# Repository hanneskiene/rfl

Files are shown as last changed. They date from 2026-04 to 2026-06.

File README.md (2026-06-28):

# rfl
4ch RC receiver/transmitter with switched diversity antennas to retrofit 35MHz remotes.

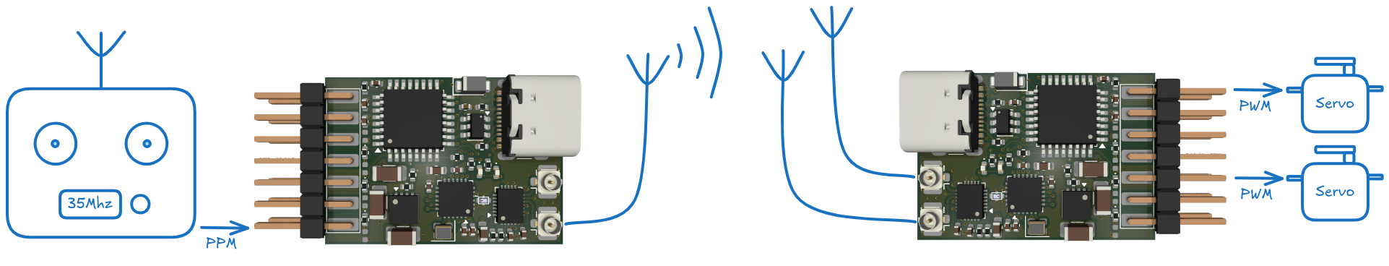
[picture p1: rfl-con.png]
Pcb Goal


- PPM input on CH3 to connect to old 35MHz internal PPM signal
- Dual U.fl connectors for antennas (single transmit, dual receive)
- 4 PWM outputs (3.3V)
- USB-C for programming 

## Parts
- SX1281 2.4GHz Transceiver IC
- SE2431L LNA/PA with up to +24 dBm
- STM32G0B1KET6N MCU
- TPS7A19 with up to 40V Vin
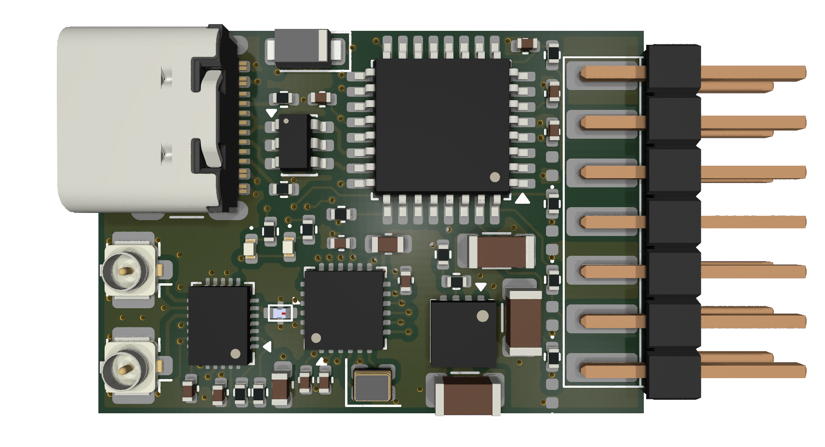
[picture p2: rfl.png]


## Assembly
QFN parts need a reflow oven/hot air station, the rest is 0402 or larger.

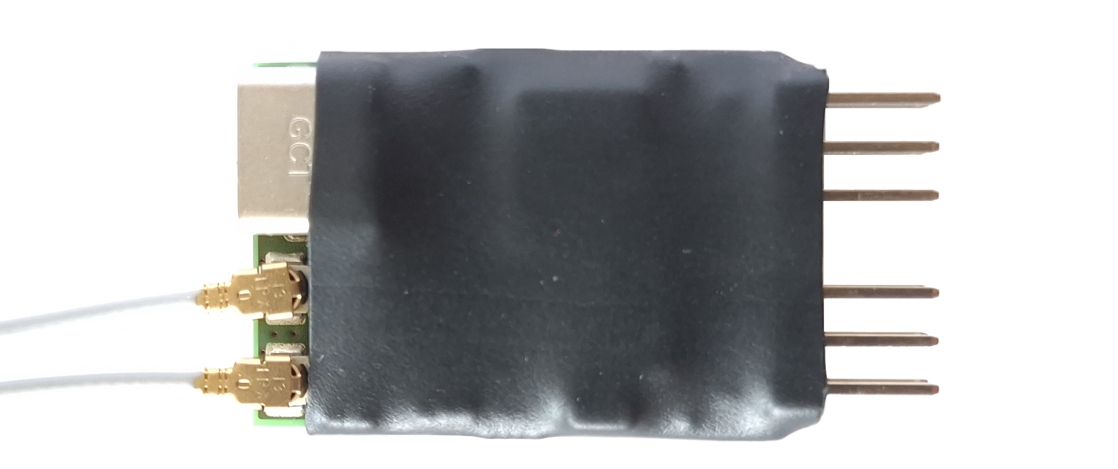
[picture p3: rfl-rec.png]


## Fimware
First prototype implementation with fixed frequency hopping table, very simple Rx-antenna diversity is "useable". The firmware currently checks for a valid PPM input if thats not found switches to receiver mode.

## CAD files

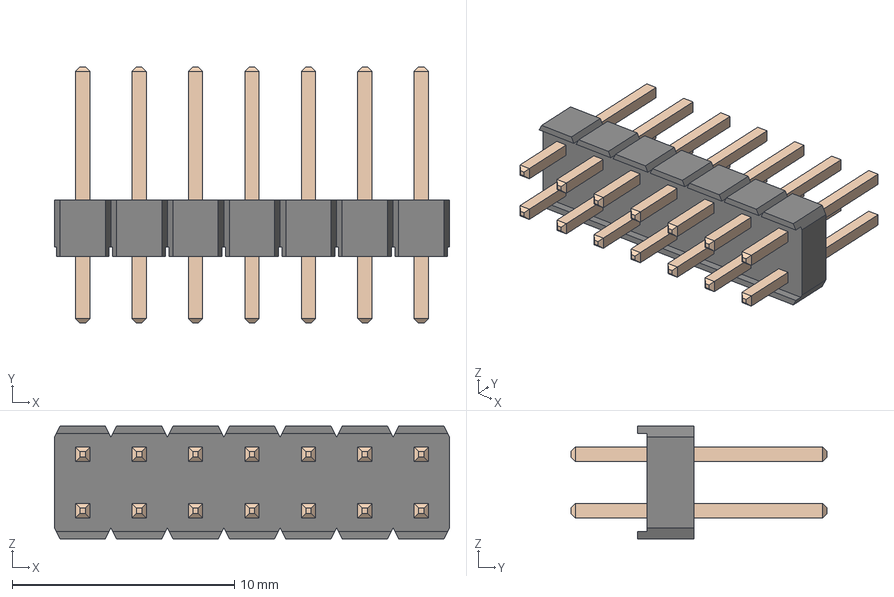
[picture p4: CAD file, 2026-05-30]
rfl/3d/Download_STP_61301421121 (rev1).stp
17.8 x 11.5 x 5.08 mm
6130xx21121_PIN x 14

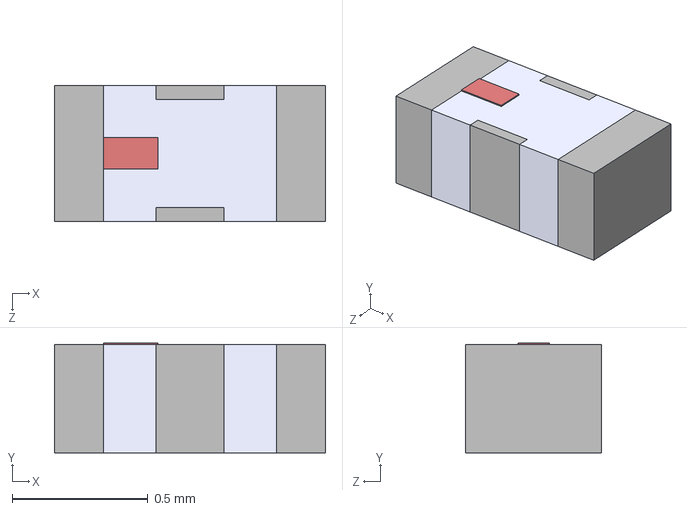
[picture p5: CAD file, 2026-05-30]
rfl/3d/2450FM07D0034001T.stp
1.00 x 0.405 x 0.5 mm

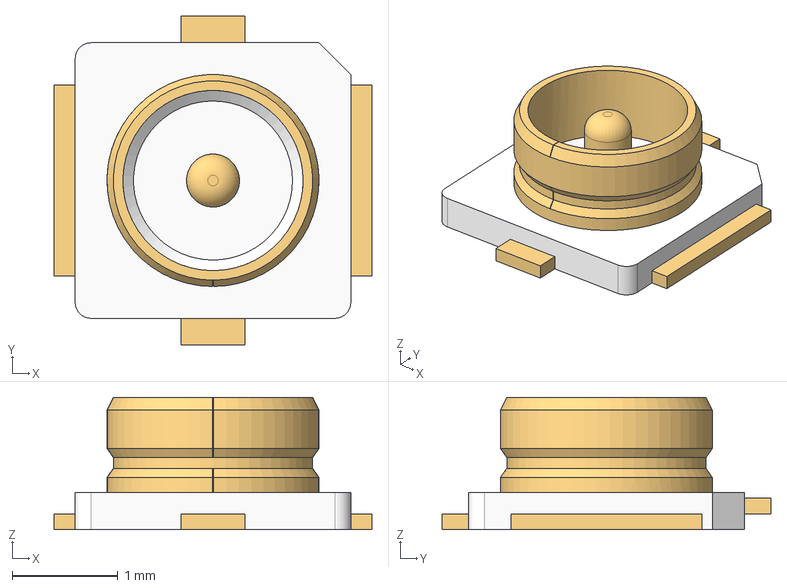
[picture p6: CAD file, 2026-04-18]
rfl/3d/Download_STP_WR-URMF_63610111x001 (rev1).stp
3.00 x 3.10 x 1.25 mm
63610111x001_Contact
63610111x001_Ground
63610111x001_Housing

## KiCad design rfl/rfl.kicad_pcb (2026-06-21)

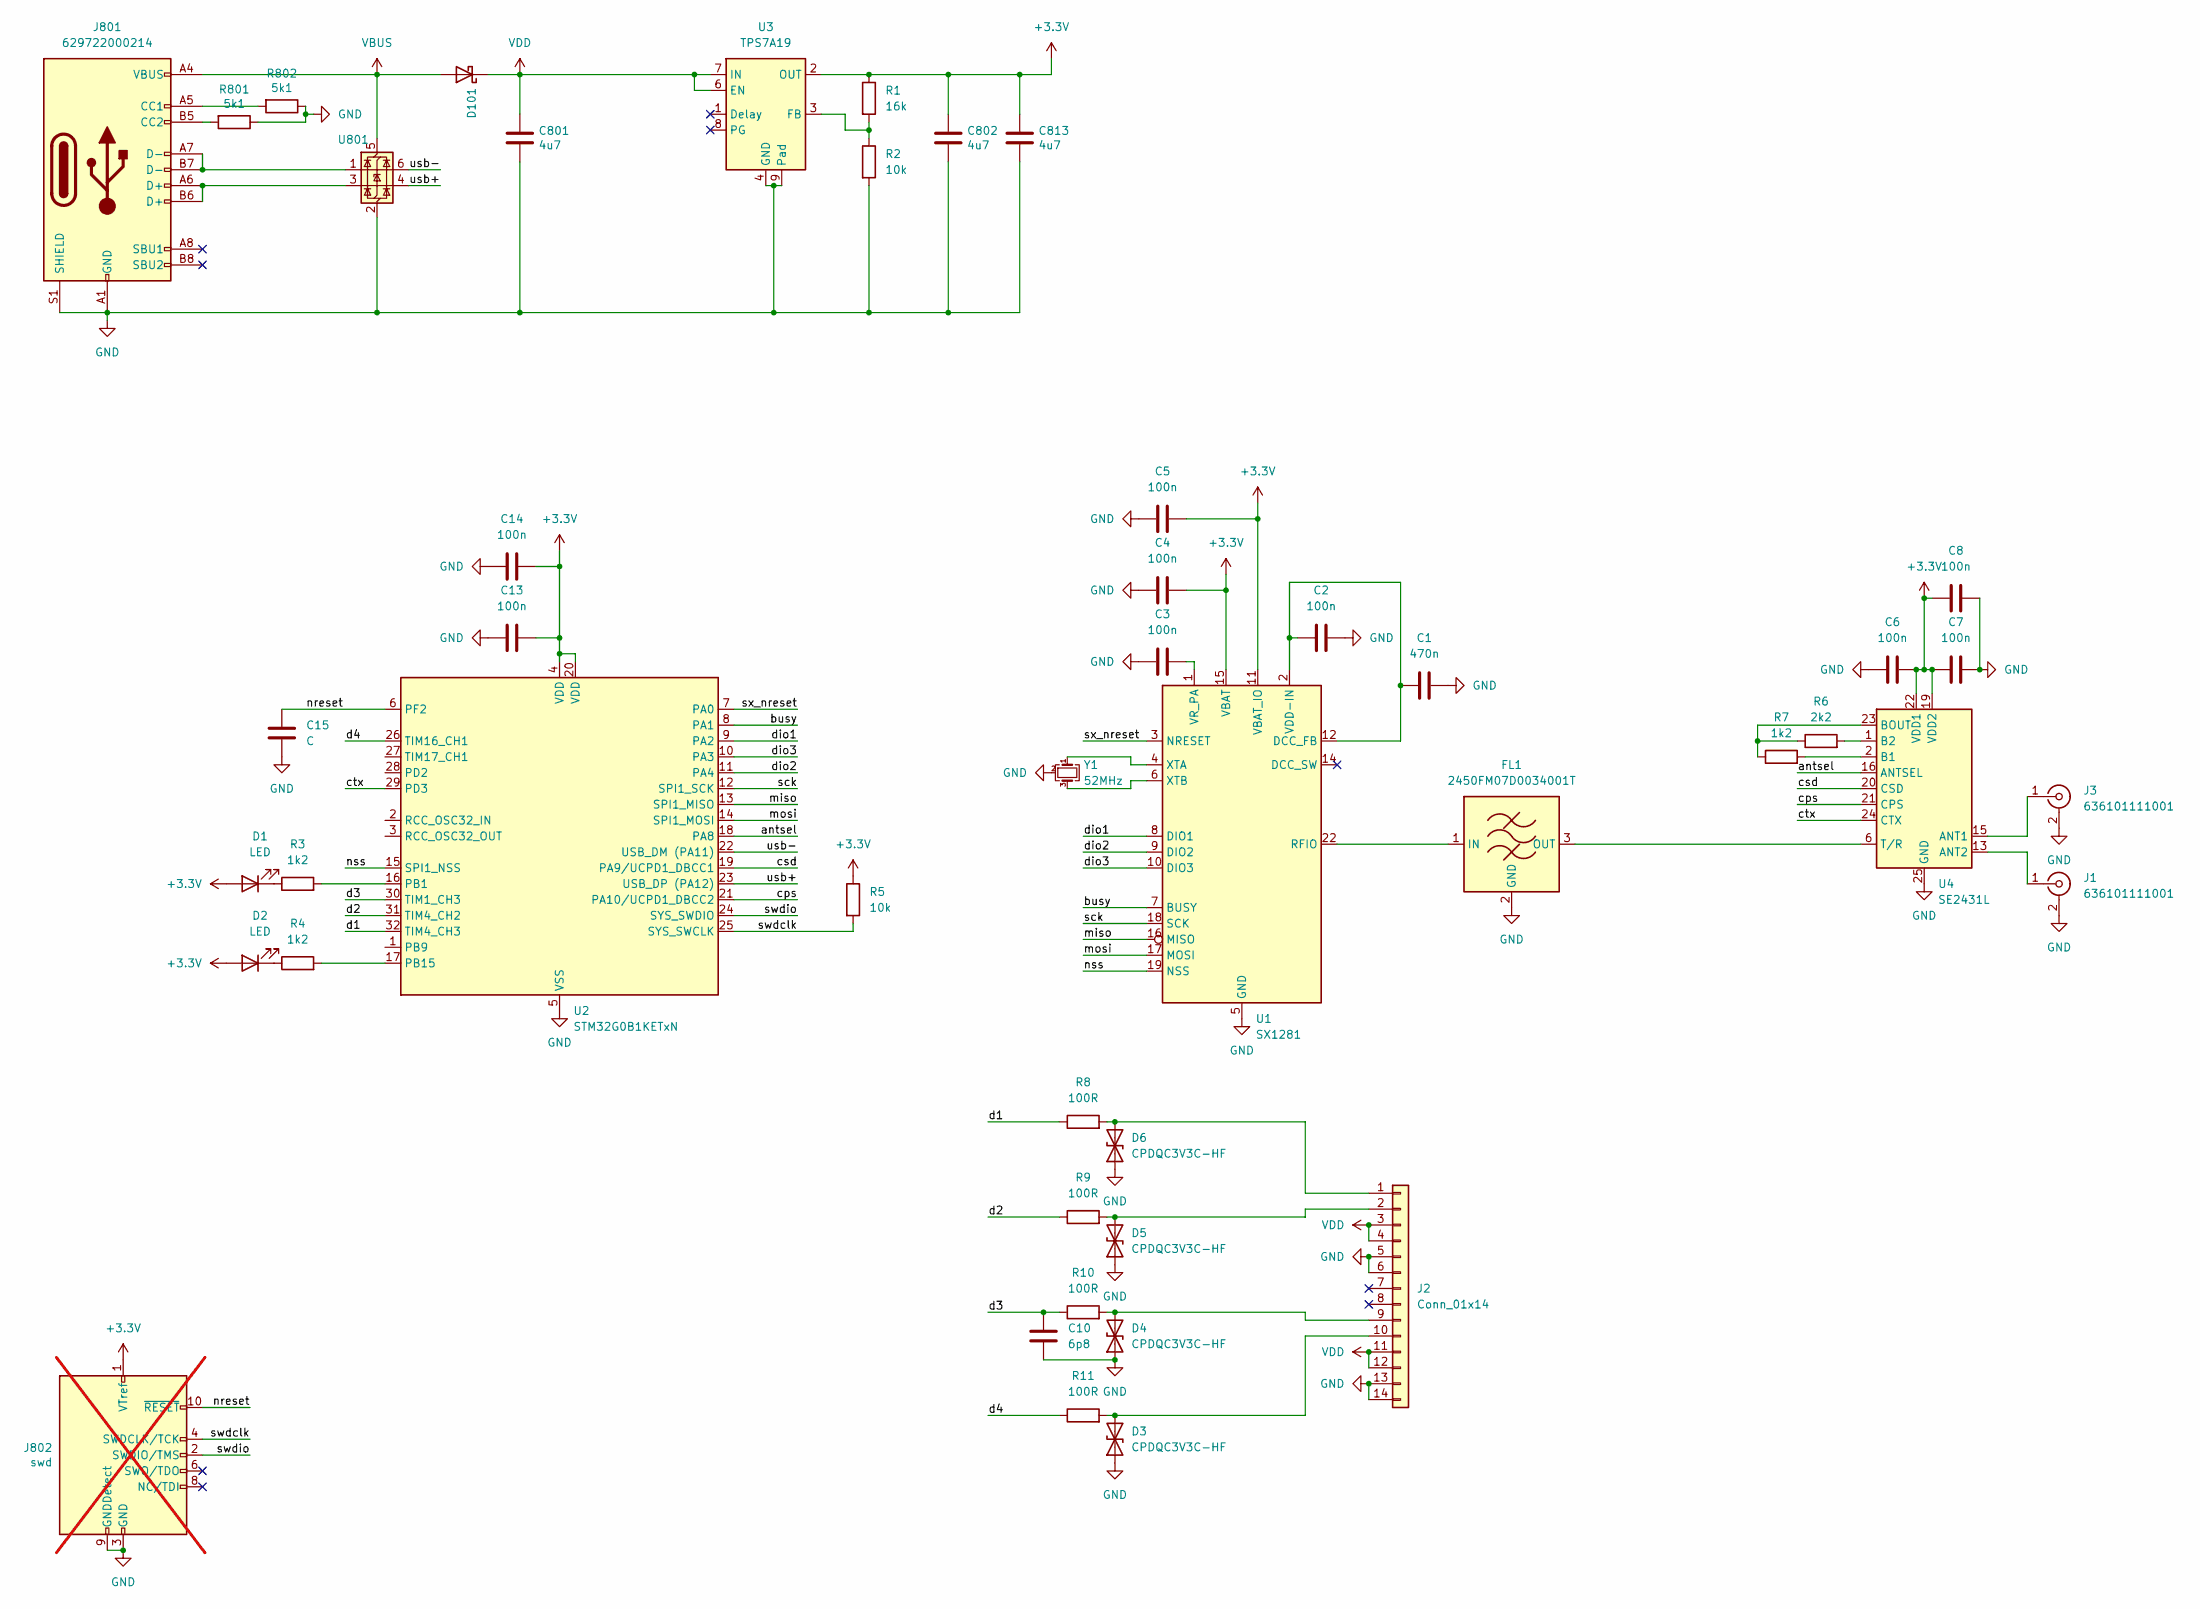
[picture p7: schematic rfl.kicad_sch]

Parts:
C1: 470n; C_0603_1608Metric
C2, C3, C4, C5, C6, C7, C13, C14: 100n; C_0402_1005Metric
C8: 100n; C_0603_1608Metric
C10: 6p8; C_0402_1005Metric
C15: C; C_0402_1005Metric
C801, C802, C813: 4u7; C_1206_3216Metric; Rating >=50V, X7R
D1, D2: LED; LED_0402_1005Metric
D3, D4, D5, D6: CPDQC3V3C-HF; D_0402_1005Metric
D101: D_SMF; PartNo V3FL45HM3/H
FL1: 2450FM07D0034001T
J1, J3: 636101111001; U.FL_Hirose_U.FL-R-SMT-1_Vertical
J2: Conn_01x14; PinHeader_2x07_P2.54mm_Edge; PartNo 61301421121
J801: 629722000214; USB_C_Receptacle_GCT_USB4105-xx-A_16P_TopMnt_Horizontal; PartNo USB4105-GF-A
J802: swd; PinHeader_2x05_P1.27mm_Vertical_SMD; PartNo e.g. FTSH-105-01-L-DV-K; not fitted
R1: 16k; R_0402_1005Metric
R2, R5: 10k; R_0402_1005Metric
R3, R4, R7: 1k2; R_0402_1005Metric
R6: 2k2; R_0402_1005Metric
R8, R9, R10, R11: 100R; R_0402_1005Metric
R801, R802: 5k1; R_0402_1005Metric
U1: SX1281; QFN-24-1EP_4x4mm_P0.5mm_EP2.6x2.6mm
U2: STM32G0B1KETxN; LQFP-32_7x7mm_P0.8mm
U3: TPS7A19; VSON-8-1EP_3x3mm_P0.65mm_EP1.65x2.4mm
U4: SE2431L; QFN-24-1EP_3x4mm_P0.4mm_EP1.65x2.65mm
U801: USBLC6-2SC6; SOT-23-6; PartNo USBLC6-2SC6
Y1: 52MHz; Crystal_SMD_2016-4Pin_2.0x1.6mm; PartNo NX2016SA-52.000000MHZ

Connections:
+3.3V: C4.2, C5.2, C6.2, C7.1, C8.1, C13.2, C14.2, C802.1, C813.1, D1.2 (A), D2.2 (A), J802.1 (VTref), R1.1, R5.1, U1.11 (VBAT_IO), U1.15 (VBAT), U2.4 (VDD), U2.20 (VDD), U3.2 (OUT), U4.19 (VDD2), U4.22 (VDD1)
/antsel: U2.18 (PA8), U4.16 (ANTSEL)
/busy: U1.7 (BUSY), U2.8 (PA1)
/cps: U2.21 (PA10/UCPD1_DBCC2), U4.21 (CPS)
/csd: U2.19 (PA9/UCPD1_DBCC1), U4.20 (CSD)
/ctx: U2.29 (PD3), U4.24 (CTX)
/d1: R8.1, U2.32 (TIM4_CH3)
/d2: R9.1, U2.31 (TIM4_CH2)
/d3: C10.2, R10.1, U2.30 (TIM1_CH3)
/d4: R11.1, U2.26 (TIM16_CH1)
/dio1: U1.8 (DIO1), U2.9 (PA2)
/dio2: U1.9 (DIO2), U2.11 (PA4)
/dio3: U1.10 (DIO3), U2.10 (PA3)
/miso: U1.16 (MISO), U2.13 (SPI1_MISO)
/mosi: U1.17 (MOSI), U2.14 (SPI1_MOSI)
/nreset: C15.2, J802.10 (~RESET), U2.6 (PF2)
/nss: U1.19 (NSS), U2.15 (SPI1_NSS)
/sck: U1.18 (SCK), U2.12 (SPI1_SCK)
/swdclk: J802.4 (SWDCLK/TCK), R5.2, U2.25 (SYS_SWCLK)
/swdio: J802.2 (SWDIO/TMS), U2.24 (SYS_SWDIO)
/sx_nreset: U1.3 (NRESET), U2.7 (PA0)
/usb+: U2.23 (USB_DP (PA12)), U801.4 (I/O2)
/usb-: U2.22 (USB_DM (PA11)), U801.6 (I/O1)
GND: C1.2, C2.2, C3.1, C4.1, C5.1, C6.1, C7.2, C8.2, C10.1, C13.1, C14.1, C15.1, C801.2, C802.2, C813.2, D3.1 (A1), D4.1 (A1), D5.1 (A1), D6.1 (A1), FL1.2 (GND), FL1.4 (GND), J1.2 (Ext), J2.5, J2.6, J2.13, J2.14, J3.2 (Ext), J801.A1 (GND), J801.A12 (GND), J801.B1 (GND), J801.B12 (GND), J801.S1 (SHIELD), J802.3 (GND), J802.5 (GND), J802.9 (GNDDetect), R2.2, R801.1, R802.1, U1.5 (GND), U1.13 (GND), U1.20 (GND), U1.21 (GND), U1.23 (GND), U1.24 (GND), U1.25 (GND), U2.5 (VSS), U3.4 (GND), U3.5 (GND), U3.9 (Pad), U4.9 (GND), U4.10 (GND), U4.11 (GND), U4.12 (GND), U4.14 (GND), U4.18 (GND), U4.25 (GND), U801.2 (GND), Y1.2 (G), Y1.4 (G)
unnamed: D1.1 (K), R3.1
unnamed: D2.1 (K), R4.1
unnamed: D3.2 (A2), J2.10, R11.2
unnamed: D4.2 (A2), J2.9, R10.2
unnamed: D5.2 (A2), J2.2, R9.2
unnamed: D6.2 (A2), J2.1, R8.2
unnamed: FL1.1 (IN), U1.22 (RFIO)
unnamed: FL1.3 (OUT), U4.6 (T/R)
unnamed: J1.1 (In), U4.13 (ANT2)
unnamed: J3.1 (In), U4.15 (ANT1)
unnamed: J801.A5 (CC1), R802.2
unnamed: J801.B5 (CC2), R801.2
unnamed: J801.A6 (D+), J801.B6 (D+), U801.3 (I/O2)
unnamed: J801.A7 (D-), J801.B7 (D-), U801.1 (I/O1)
unnamed: C1.1, C2.1, U1.2 (VDD-IN), U1.12 (DCC_FB)
unnamed: C3.2, U1.1 (VR_PA)
unnamed: U1.4 (XTA), Y1.1
unnamed: U1.6 (XTB), Y1.3
unnamed: R3.2, U2.16 (PB1)
unnamed: R4.2, U2.17 (PB15)
unnamed: R1.2, R2.1, U3.3 (FB)
unnamed: R7.2, U4.2 (B1)
unnamed: R6.2, U4.1 (B2)
unnamed: R6.1, R7.1, U4.23 (BOUT)
VBUS: D101.2 (A), J801.A4 (VBUS), J801.A9 (VBUS), J801.B4 (VBUS), J801.B9 (VBUS), U801.5 (VBUS)
VDD: C801.1, D101.1 (K), J2.3, J2.4, J2.11, J2.12, U3.6 (EN), U3.7 (IN)

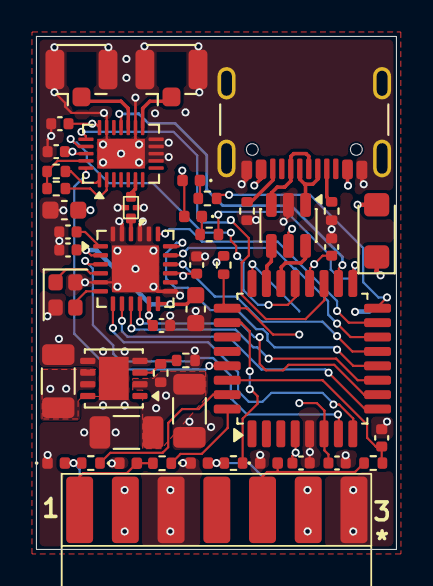
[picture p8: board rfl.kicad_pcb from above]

Board: 4 copper layers, 20.0 x 28.5 mm, 47 parts (1 on the bottom side), 50 nets.

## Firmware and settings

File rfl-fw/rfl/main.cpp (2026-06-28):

/*
 * main.cpp
 *
 *  Created on: Jun 14, 2026
 *      Author: hannes
 */

#include "main.h"
#include <stdio.h>

#include "usbd_cdc_if.h"

#include "boot_config.hpp"
#include "sx128x_stm.hpp"
#include "sender.hpp"
#include "receiver.hpp"

#include "pwm_out.hpp"
#include "ppm_in.hpp"

extern "C" int _write(int file, char *ptr, int len) {
    CDC_Transmit_FS((uint8_t*) ptr, len);
    return len;
}
extern "C" int _read(int file, char *ptr, int len)
{
    while (!rx_ready)
    {
        // wait for USB data
    }

    *ptr = rx_char;
    rx_ready = 0;

    return 1;
}

int main()
{
  early_configure_option_bytes();
  init();

  uint32_t devid = HAL_GetUIDw0() ^ HAL_GetUIDw1() ^ HAL_GetUIDw2();

  SX1281 sx{SPI1, sx_cs_GPIO_Port, sx_cs_Pin, sx_busy_GPIO_Port, sx_busy_Pin, sx_nreset_GPIO_Port, sx_nreset_Pin,
  sky_cps_GPIO_Port, sky_cps_Pin, sky_csd_GPIO_Port, sky_csd_Pin, sky_ctx_GPIO_Port, sky_ctx_Pin, sky_antsel_GPIO_Port, sky_antsel_Pin};

  sx.begin();

  char mode = 'r';
  Sender s{sx};
  Receiver r{sx};

  PwmOut pwm{};
  PPMInput ppm{};
  ppm.start();
  HAL_Delay(500);
  if(ppm.frameValid){
	  mode = 's';
  }else{
	  mode = 'r';
	  ppm.stop();
	  pwm.start();
  }

  uint32_t last_status_ts{};
  while(true){
	  LL_IWDG_ReloadCounter(IWDG);
	  if(rx_ready){
		  LL_GPIO_TogglePin(led1_GPIO_Port, led1_Pin);
		  char c = getchar();
		  switch (c){
			  case 'd': printf("OK\n"); break;
			  case 'r': mode = 'r'; printf("Mode Receiver\n"); break;
			  case 's': mode = 's'; printf("Mode Sender\n");break;
			  case 'i': printf("%i, %i, %i, %i, at %ims and %idBm\n", r.channels[0], r.channels[1], r.channels[2], r.channels[3], (int)r.avg_delta,  r.lastRSSI); break;
			  case 'b': enter_bootloader(1234); break;
			  case 'c': while(true){} break;
		  }
	  }
	  switch(mode){
	  case 'r':{
		  r.tick();
		  if(r.receiving()) pwm.set(r.channels[0], r.channels[1], r.channels[2], r.channels[3]);
		  else pwm.set(1500, 1500, 1000, 1500);
		  //if(HAL_GetTick() - last_status_ts > 1000){last_status_ts = HAL_GetTick(); printf("Rx %i %ims %idBm\n", ppm.channels[0], (int)r.avg_delta, r.lastRSSI);}
		  break;
	  }
	  case 's':{
		  for(int i = 0; i < 4; i++){s.channels[i] = ppm.channels[i];}
		  s.tick();
		  break;
	  }
	  default: break;
	  }
  }
}

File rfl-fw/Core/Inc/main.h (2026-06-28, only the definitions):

#define sx_nreset_Pin LL_GPIO_PIN_0
#define sx_nreset_GPIO_Port GPIOA
#define sx_busy_Pin LL_GPIO_PIN_1
#define sx_busy_GPIO_Port GPIOA
#define sx_dio1_Pin LL_GPIO_PIN_2
#define sx_dio1_GPIO_Port GPIOA
#define sx_dio3_Pin LL_GPIO_PIN_3
#define sx_dio3_GPIO_Port GPIOA
#define sx_dio2_Pin LL_GPIO_PIN_4
#define sx_dio2_GPIO_Port GPIOA
#define sx_cs_Pin LL_GPIO_PIN_0
#define sx_cs_GPIO_Port GPIOB
#define led2_Pin LL_GPIO_PIN_1
#define led2_GPIO_Port GPIOB
#define led1_Pin LL_GPIO_PIN_15
#define led1_GPIO_Port GPIOB
#define sky_antsel_Pin LL_GPIO_PIN_8
#define sky_antsel_GPIO_Port GPIOA
#define sky_csd_Pin LL_GPIO_PIN_9
#define sky_csd_GPIO_Port GPIOA
#define sky_cps_Pin LL_GPIO_PIN_10
#define sky_cps_GPIO_Port GPIOA
#define d4_Pin LL_GPIO_PIN_0
#define d4_GPIO_Port GPIOD
#define sky_ctx_Pin LL_GPIO_PIN_3
#define sky_ctx_GPIO_Port GPIOD
#define d3_Pin LL_GPIO_PIN_6
#define d3_GPIO_Port GPIOB
#define d2_Pin LL_GPIO_PIN_7
#define d2_GPIO_Port GPIOB
#define d1_Pin LL_GPIO_PIN_8
#define d1_GPIO_Port GPIOB

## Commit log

2026-05-30 before switch
    [rfl.kicad_pcb, rfl.kicad_sch]
2026-05-30 v2 with rf switch wip
    [rfl.kicad_pcb, rfl.kicad_sch]
2026-05-30 more files
    [2450FM07D0034001T.stp, Download_STP_61301421121 (rev1).stp]
2026-05-31 cleaned up layout
    [rfl.kicad_pcb]
2026-05-31 fixed edge cleareance
    [rfl.kicad_pcb, rfl.kicad_sch]
2026-06-21 first working rec/send rc
    [rfl.kicad_pcb, rfl.kicad_sch]

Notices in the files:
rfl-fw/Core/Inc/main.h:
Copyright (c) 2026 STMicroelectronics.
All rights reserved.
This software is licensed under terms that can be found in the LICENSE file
